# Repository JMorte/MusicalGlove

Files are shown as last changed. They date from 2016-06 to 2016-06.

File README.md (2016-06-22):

# MusicalGlove

The directories are structured by this way:

Arduino folder contains the Processing code of the Transmitter and the receiver.
Design folder includes the Hardware design, the schematic and board with its corresponding images.
Video folder have two demonstrations of the features of the glove.

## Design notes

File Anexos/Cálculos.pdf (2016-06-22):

# CÁLCULO DE CONSUMO

Resistencias de pull down:

Cada resistencia:

I =

3
R

= 3 ∗ 10⁻⁴ = 0.3mA

En total, suponiendo que pulsamos durante 500 milisegundos / segundo:

0.5 ∗ 0.3 ∗ 5 = 0.75mA

Aproximamos a 1mA.

Módulo NRF24L01:

En transmisión el módulo consume 11.3mA, y el tiempo de stand-by consume 26uA. Transmite datos durante 4ms, y espera 30ms, por lo que consume:

I =

11.3 ∗ 4 + 0.026 ∗ 30
34 | = 1.35mA

El consumo sería 1.35mA en el caso de que el módulo no pierda ninguna trama y no tenga que retransmitir. Como este escenario es ideal, suponemos que está más tiempo transmitiendo.

Aproximamos a 2mA.

Microprocesador Atmega 328P-PU:

El consumo del microprocesador lo hemos estimado a partir del datasheet, ya que el consumo exacto de nuestro escenario de trabajo no aparece.

Aproximamos a 15mA.

Giroscopio L3GD20h:

El consumo del giroscopio lo hemos obtenido del datasheet: 6.1mA.

Aproximamos a 7mA.

En total obtenemos: 1 + 2 + 15 + 7= 25mA

Alimentamos con dos pilas (AA) de 2000mA, las horas aproximadas de funcionamiento son:

Duración Batería =

2 ∗ 2000
25 = 160 ℎoras

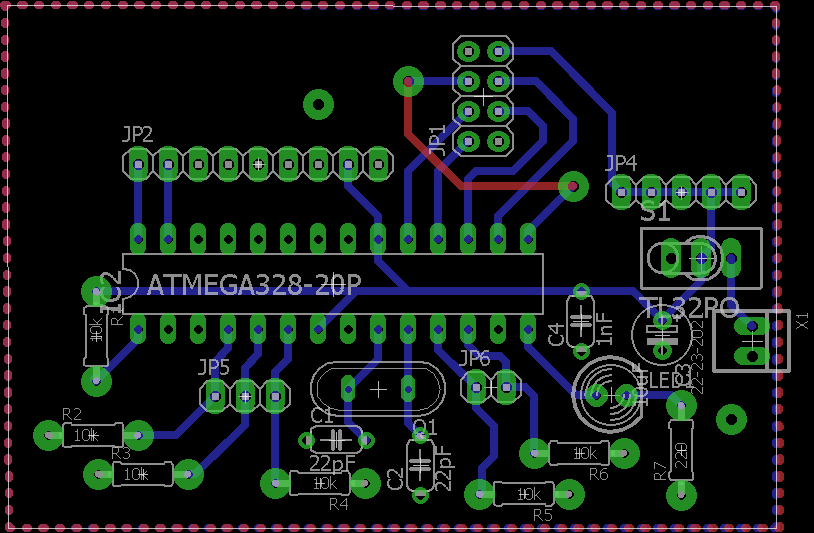
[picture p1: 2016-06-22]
Design/Transmitter/PCB_transmitter.png

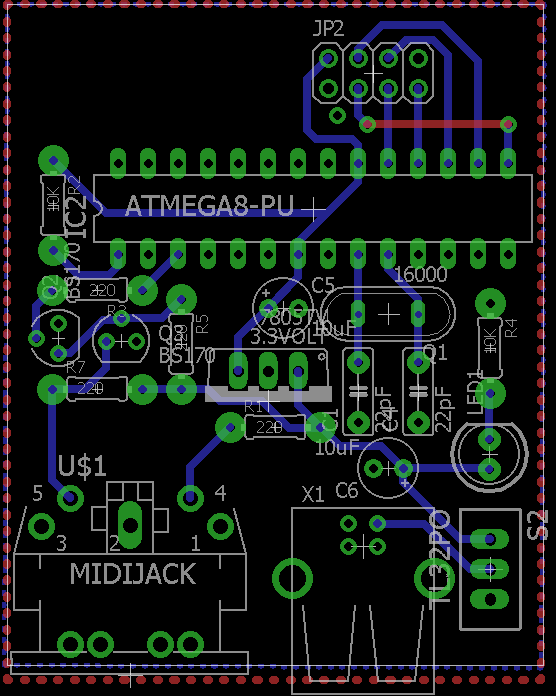
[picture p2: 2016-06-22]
Design/Receiver/PCB_receiver.png

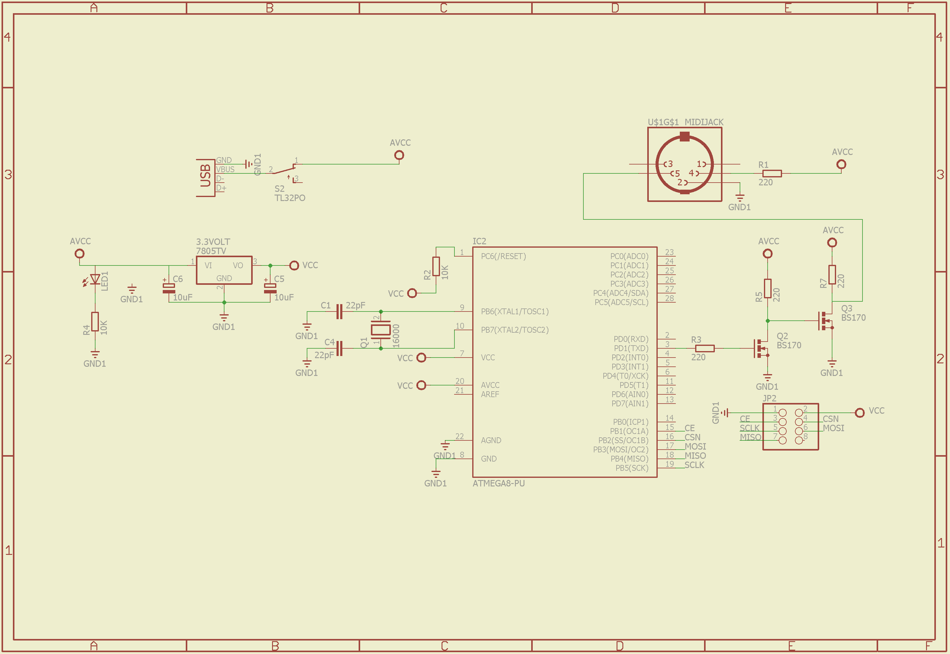
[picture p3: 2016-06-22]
Design/Receiver/sch_receiver.png

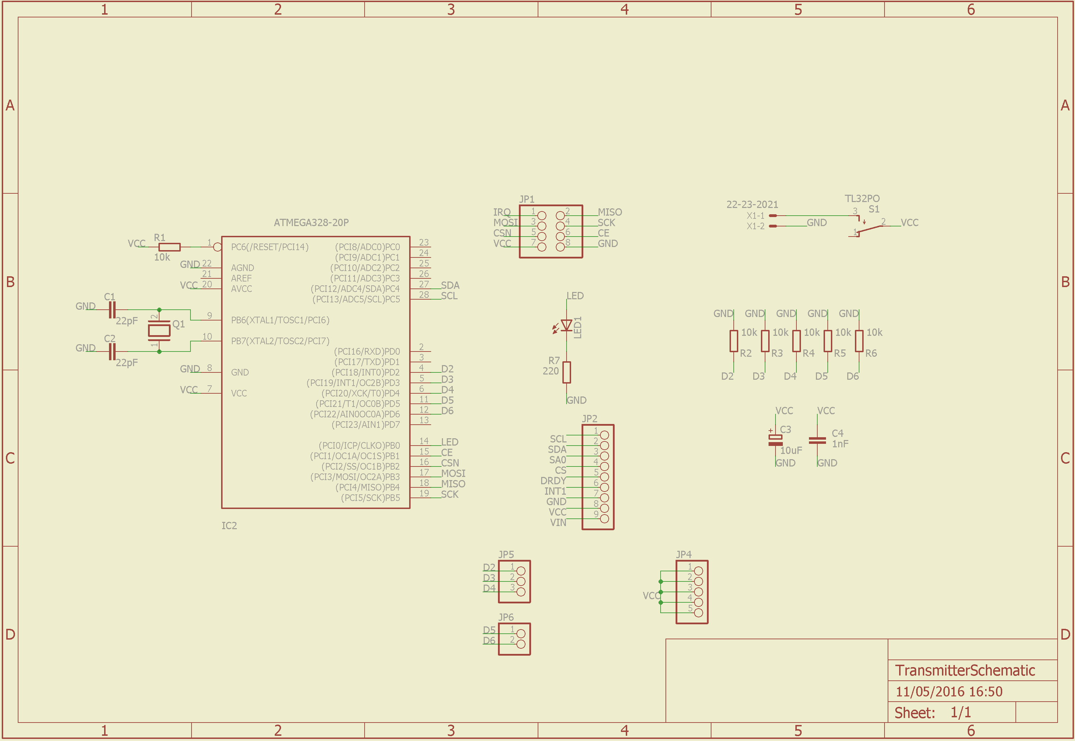
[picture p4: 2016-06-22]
Design/Transmitter/sch_transmitter.png

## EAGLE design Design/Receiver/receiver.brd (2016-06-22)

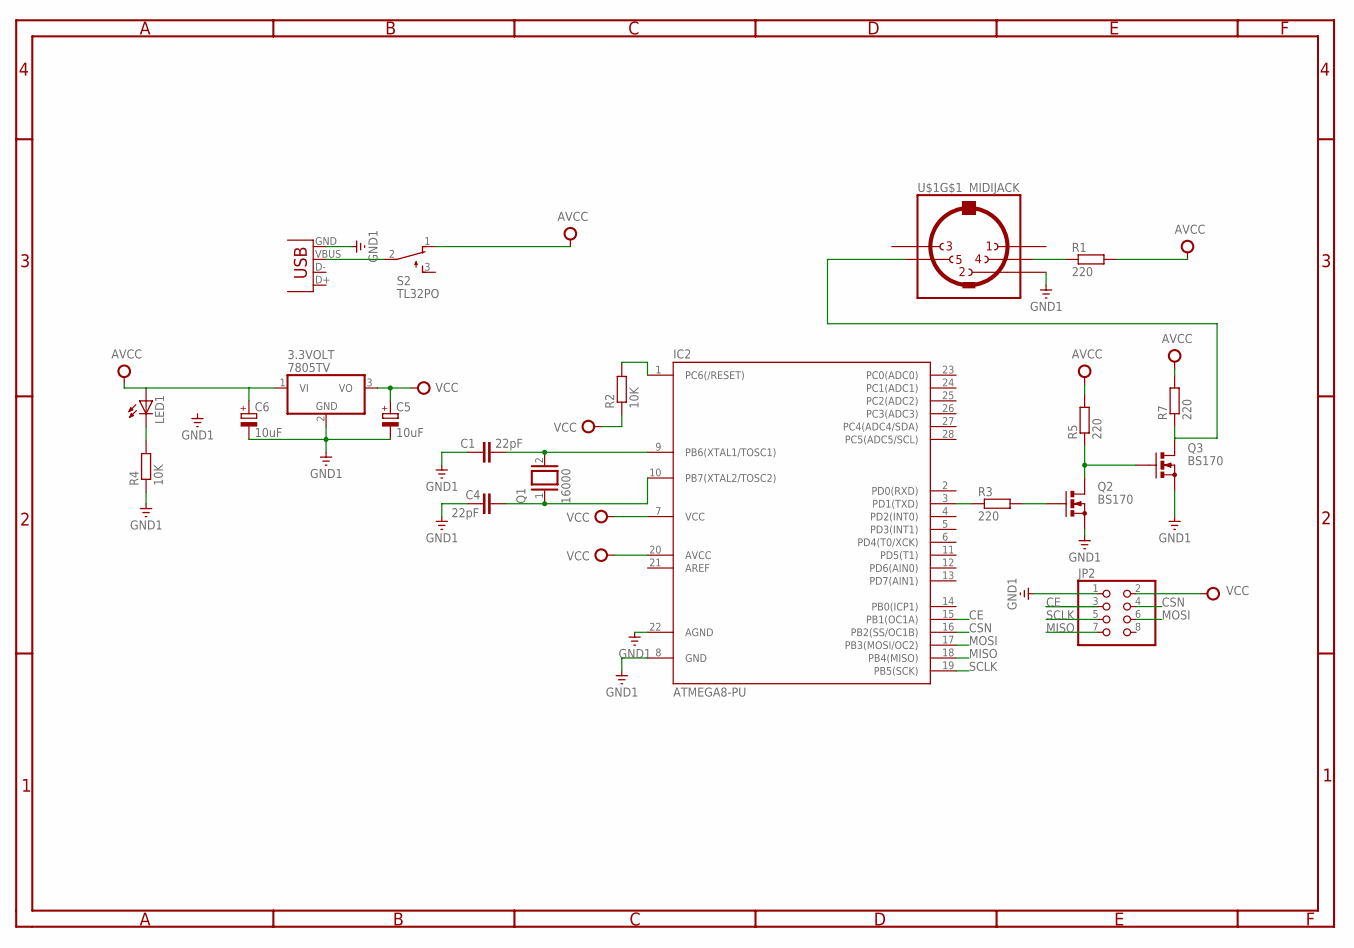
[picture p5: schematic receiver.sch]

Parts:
3.3VOLT: 7805TV; TO220V
C1, C4: 22pF; C050-025X075
C5, C6: 10uF; E2,5-5
IC2: ATMEGA8-PU; DIL28-3
JP2: PINHD-2X4; 2X04
LED1: LED5MM
Q1: 16000; QS
Q2, Q3: BS170; SOT54E
R1, R3, R5, R7: 220; 0204/7
R2, R4: 10K; 0204/7
S2: TL32PO; TL3XPO
U$1: MIDIJACK; CP-2350
X1: USB-B-H

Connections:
AVCC: 3.3VOLT.1 (VI), C6.+, LED1.A, R1.2, R5.2, R7.2, S2.1 (O)
CE: IC2.15 (PB1(OC1A)), JP2.3
CSN: IC2.16 (PB2(SS/OC1B)), JP2.4
GND1: 3.3VOLT.2 (GND), C1.1, C4.1, C5.-, C6.-, IC2.8 (GND), IC2.22 (AGND), JP2.1, Q2.S, Q3.S, R4.1, U$1.2, X1.GND
MISO: IC2.18 (PB4(MISO)), JP2.7
MOSI: IC2.17 (PB3(MOSI/OC2)), JP2.6
unnamed: C1.2, IC2.9 (PB6(XTAL1/TOSC1)), Q1.2
unnamed: C4.2, IC2.10 (PB7(XTAL2/TOSC2)), Q1.1
unnamed: S2.2, X1.VBUS
unnamed: LED1.K (C), R4.2
unnamed: IC2.3 (PD1(TXD)), R3.1
unnamed: Q2.G, R3.2
unnamed: IC2.1 (PC6(/RESET)), R2.2
unnamed: Q2.D, Q3.G, R5.1
unnamed: R1.1, U$1.4
unnamed: Q3.D, R7.1, U$1.5
SCLK: IC2.19 (PB5(SCK)), JP2.5
VCC: 3.3VOLT.3 (VO), C5.+, IC2.7 (VCC), IC2.20 (AVCC), JP2.2, R2.1

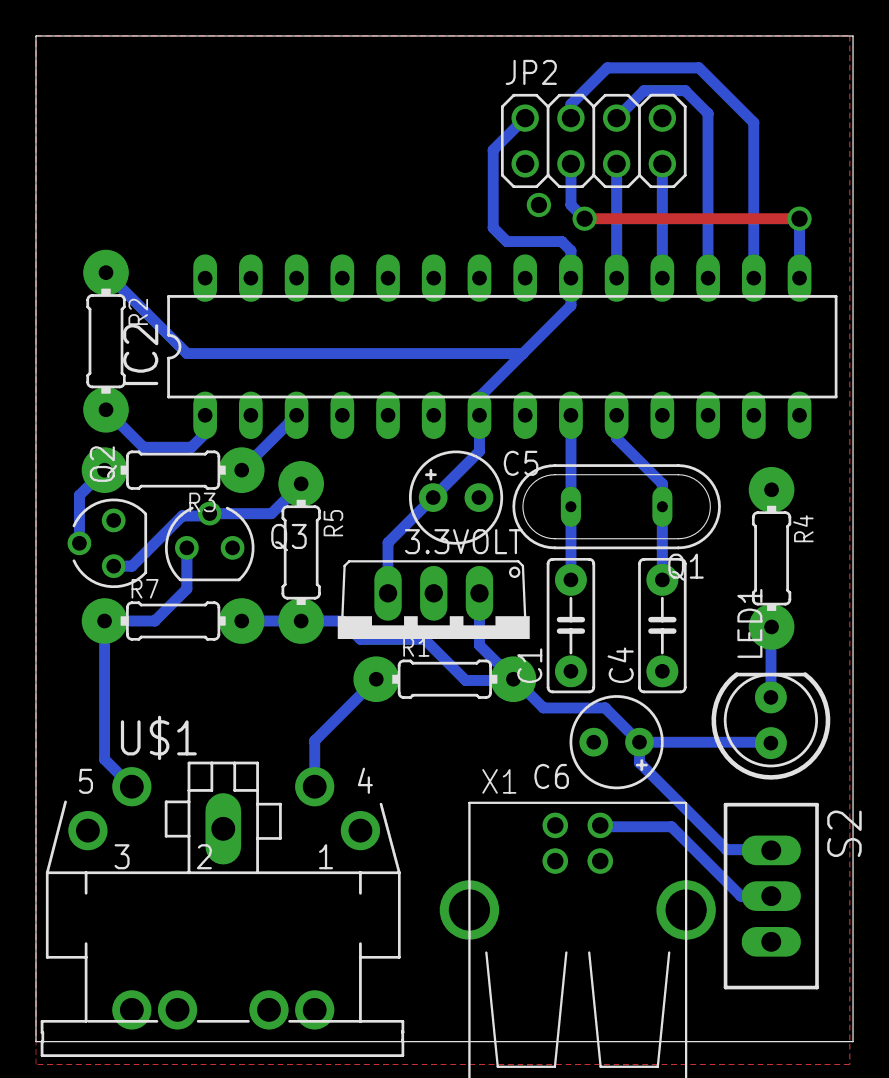
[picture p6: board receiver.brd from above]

Board: 2 copper layers, 45.4 x 55.9 mm, 20 parts (0 on the bottom side), 18 nets.

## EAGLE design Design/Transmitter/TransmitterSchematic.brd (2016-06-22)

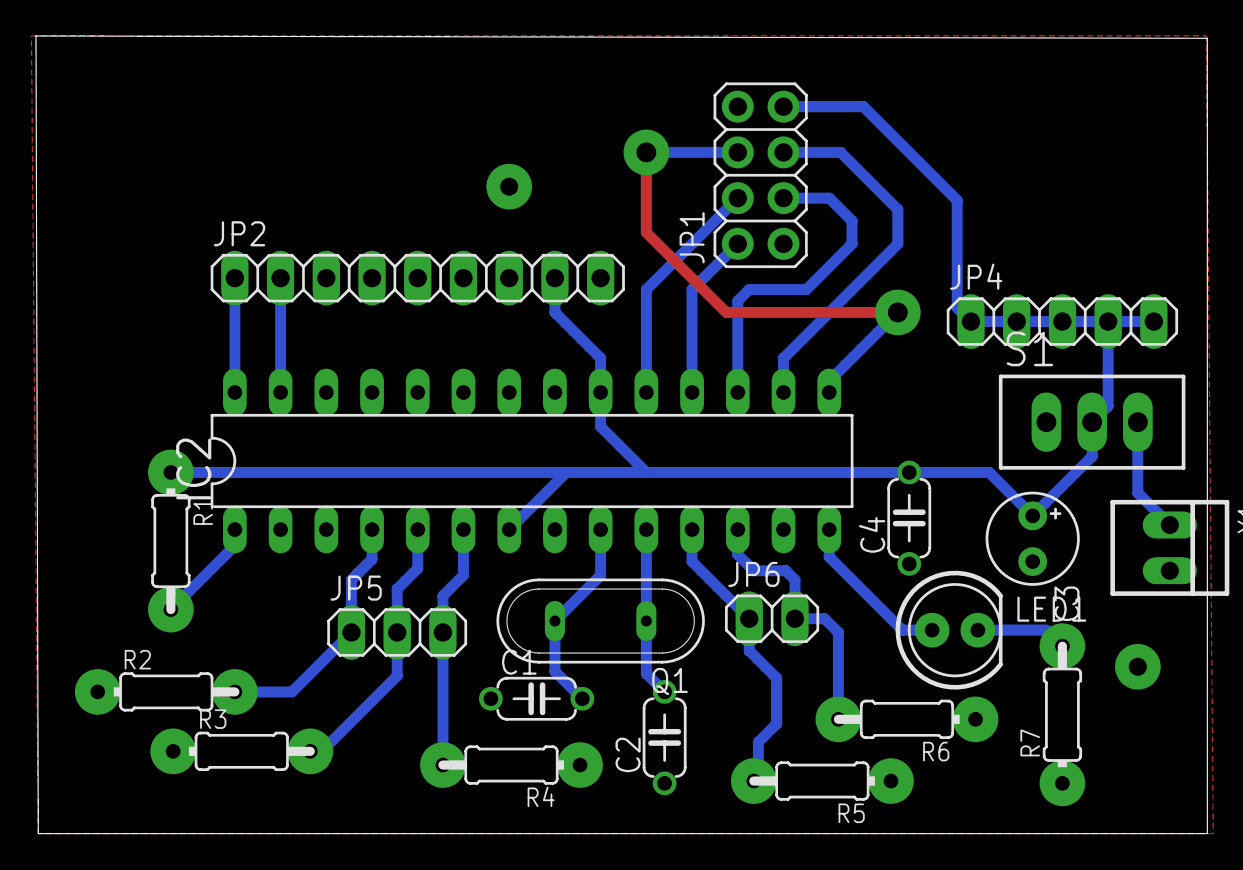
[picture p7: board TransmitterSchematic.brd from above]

Board: 2 copper layers, 65.1 x 44.3 mm, 21 parts (0 on the bottom side), 20 nets.

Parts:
C1, C2: 22pF; C050-024X044
C3: 10uF; E2,5-5
C4: 1nF; C050-024X044
IC2: ATMEGA328-20P; DIL28-3
JP1: 2X04
JP2: 1X09
JP4: 1X05
JP5: 1X03
JP6: 1X02
LED1: LED5MM
Q1: QS
R1, R2, R3, R4, R5, R6: 10k; 0204/7
R7: 220; 0204/7
S1: TL32PO; TL3XPO
X1: 22-23-2021

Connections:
CE: IC2.15, JP1.6
CSN: IC2.16, JP1.5
D2: IC2.4, JP5.1, R2.2
D3: IC2.5, JP5.2, R3.2
D4: IC2.6, JP5.3, R4.2
D5: IC2.11, JP6.1, R5.2
D6: IC2.12, JP6.2, R6.2
GND: C1.1, C2.1, C3.-, C4.1, IC2.8, IC2.22, JP1.8, JP2.7, R2.1, R3.1, R4.1, R5.1, R6.1, R7.1, X1.2
LED: IC2.14, LED1.A
MISO: IC2.18, JP1.2
MOSI: IC2.17, JP1.3
unnamed: C1.2, IC2.9, Q1.2
unnamed: C2.2, IC2.10, Q1.1
unnamed: IC2.1, R1.2
unnamed: LED1.K, R7.2
unnamed: S1.3, X1.1
SCK: IC2.19, JP1.4
SCL: IC2.28, JP2.1
SDA: IC2.27, JP2.2
VCC: C3.+, C4.2, IC2.7, IC2.20, JP1.7, JP2.8, JP4.1, JP4.2, JP4.3, JP4.4, JP4.5, R1.1, S1.2

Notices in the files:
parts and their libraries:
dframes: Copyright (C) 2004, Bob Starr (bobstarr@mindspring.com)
